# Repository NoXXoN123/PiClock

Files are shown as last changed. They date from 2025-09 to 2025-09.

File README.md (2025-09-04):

# PiClock
An Original design of an Analog Digital Clock featuring over 210 LEDs and full customization!

# License
Copyright 2025 NoXXoN

All Rights Reserved.

You may view, download, and manufacture physical copies of this PCB and schematic design for **personal, non-commercial use only** (e.g., DIY projects or prototyping).

You may **not**:
- Distribute, share, or sell the design files or derived works.
- Manufacture boards for sale, resale, or commercial deployment.
- Host or mirror this content online.

For commercial licensing, manufacturing rights, or redistribution permissions, please contact:
noxxonyt@gmail.com

This license applies to all files in this project unless explicitly stated otherwise.

# Schematic
Schematic <br>

# PCB and schematic files
PCB: https://github.com/NoXXoN123/PiClock/blob/main/ClockPi.kicad_pcb  
Schematic: https://github.com/NoXXoN123/PiClock/blob/main/ClockPi.kicad_sch  
Kicad_Pro: https://github.com/NoXXoN123/PiClock/blob/main/ClockPi.kicad_pro  
# How to install
Install Thonny, Install MicroPython on a Pi Pico, Save the code below as 'main.py' on the directory of the Raspberry Pi by opening File Manager in Thonny (View > Files) or use Save As and choose the Raspberry Pi.  
# Code:
main.py:

```
import time
from machine import Pin, PWM, ADC

def percent_to_duty(pct):
    return int((pct / 100.0) * 65535)

def get_light_level():
    raw = light_sensor.read_u16()     # 0–65535
    return raw >> 8                   # Scale to 0–255

def set_pwm_all(level):
    pwm_seconds.duty_u16(level)
    pwm_minutes.duty_u16(level)
    pwm_hours.duty_u16(level)

def light_control_loop():
    while True:
        light = get_light_level()

        if light < LIGHT_THRESHOLD:
            set_pwm_all(DIM_LEVEL)
        else:
            set_pwm_all(BRIGHT_LEVEL)

        time.sleep(0.1)  # Check every 100ms
def shift_out(data_pin, clock_pin, latch_pin, data_bytes):
    latch_pin.value(0)
    for byte in data_bytes:
        for bit in range(8):
            data_pin.value((byte >> (7 - bit)) & 1)
            clock_pin.value(1)
            clock_pin.value(0)
    latch_pin.value(1)
def seconds(*bits):
    # bits is a list of 64 bits for 8 chips * 8 bits
    # convert bits to bytes and send
    data_bytes = []
    for i in range(0, 64, 8):
        byte = 0
        for b in bits[i:i+8]:
            byte = (byte << 1) | (b & 1)
        data_bytes.append(byte)
    shift_out(DATA_PIN_SECONDS, CLOCK_PIN_SECONDS, LATCH_PIN_SECONDS, data_bytes)

def minutes(*bits):
    data_bytes = []
    for i in range(0, 64, 8):
        byte = 0
        for b in bits[i:i+8]:
            byte = (byte << 1) | (b & 1)
        data_bytes.append(byte)
    shift_out(DATA_PIN_MINUTES, CLOCK_PIN_MINUTES, LATCH_PIN_MINUTES, data_bytes)

def hours(*bits):
    data_bytes = []
    for i in range(0, 16, 8):
        byte = 0
        for b in bits[i:i+8]:
            byte = (byte << 1) | (b & 1)
        data_bytes.append(byte)
    shift_out(DATA_PIN_HOURS, CLOCK_PIN_HOURS, LATCH_PIN_HOURS, data_bytes)
def seconds(*bits):
    # your code to shift out bits to the seconds chips
    pass

def minutes(*bits):
    # same for minutes
    pass

def hours(*bits):
    # same for hours
    pass

# Pin setup - Don't touch this!
DATA_PIN_SECONDS = Pin(2, Pin.OUT)
CLOCK_PIN_SECONDS = Pin(3, Pin.OUT)
LATCH_PIN_SECONDS = Pin(4, Pin.OUT)

DATA_PIN_MINUTES = Pin(5, Pin.OUT)
CLOCK_PIN_MINUTES = Pin(6, Pin.OUT)
LATCH_PIN_MINUTES = Pin(7, Pin.OUT)

DATA_PIN_HOURS = Pin(9, Pin.OUT)
CLOCK_PIN_HOURS = Pin(8, Pin.OUT)
LATCH_PIN_HOURS = Pin(10, Pin.OUT)

PHOTORESISTOR_PIN = 26 # ADC0
PWM_SECONDS_PIN = 19
PWM_MINUTES_PIN = 20
PWM_HOURS_PIN = 21
BUTTON_HOUR = Pin(17, Pin.IN, Pin.PULL_DOWN)
BUTTON_MINUTE = Pin(16, Pin.IN, Pin.PULL_DOWN)
LED = Pin(25, Pin.OUT)
# Setup Variables - Don't touch this either!
SECOND_CHIPS = 8
MINUTE_CHIPS = 8
HOUR_CHIPS = 2
# USER SETTINGS - Touch this!
PWM_FREQ = 1000 #Hz DEFAULT: 1000
PWM_BRIGHT = percent_to_duty(60)  # DEFAULT: 60
PWM_DIM = percent_to_duty(10)     # DEFAULT: 10
LIGHT_THRESHOLD = 100 # DEFAULT: 100
# ---------------------
light_sensor = ADC(PHOTORESISTOR_PIN)
pwm_seconds = PWM(Pin(PWM_SECONDS_PIN))
pwm_minutes = PWM(Pin(PWM_MINUTES_PIN))
pwm_hours   = PWM(Pin(PWM_HOURS_PIN))
for pwm in (pwm_seconds, pwm_minutes, pwm_hours):
    pwm.freq(PWM_FREQ)

seconds_buffer = bytearray(SECOND_CHIPS)
minutes_buffer = bytearray(MINUTE_CHIPS)
hours_buffer = bytearray(HOUR_CHIPS)

# ---------------- Functions ----------------
def boot_animation_chase():
    for i in range(64):  # 64 steps for seconds and minutes
        sec_pattern = [0 if j == i else 1 for j in range(64)]
        min_pattern = [0 if j == (i + 20) % 64 else 1 for j in range(64)]  # offset for visual effect
        hr_pattern  = [0 if j == (i % 16) else 1 for j in range(16)]       # wrap 0–15

        seconds(*sec_pattern)
        minutes(*min_pattern)
        hours(*hr_pattern)

        time.sleep(0.03)

def fast_forward_boot(cycle_duration_sec=10):
    total_seconds = 12 * 60 * 60  # 12 hours = 43200 seconds
    delay = cycle_duration_sec / total_seconds

    for seconds_passed in range(total_seconds):
        sec = seconds_passed % 60
        min = (seconds_passed // 60) % 60
        hr  = (seconds_passed // 3600) % 12  # 12-hour format

        sec_buf = [1] * 64
        sec_buf[sec] = 0  # active low
        seconds(*sec_buf)

        min_buf = [1] * 64
        min_buf[min] = 0
        minutes(*min_buf)

        hr_buf = [1] * 16
        hr_buf[hr] = 0
        hours(*hr_buf)

        time.sleep(delay)

def run_clock():
    last_sec_update = 0
    last_min_update = 0
    last_hour_update = 0

    sec = 0
    minute = 0
    hour = 0

    last_button_hour = 0
    last_button_minute = 0
    debounce_ms = 200  # debounce delay

    led_on_time = 0
    led_duration = 200  # ms to keep LED on visibly

    while True:
        now = time.ticks_ms()

        if BUTTON_HOUR.value() == 1 and time.ticks_diff(now, last_button_hour) > debounce_ms:
            hour = (hour + 1) % 12
            hours(*[0 if i == hour else 1 for i in range(16)])
            last_button_hour = now
            last_hour_update = now

        if BUTTON_MINUTE.value() == 1 and time.ticks_diff(now, last_button_minute) > debounce_ms:
            minute = (minute + 1) % 60
            minutes(*[0 if i == minute else 1 for i in range(64)])
            last_button_minute = now
            last_min_update = now

        if time.ticks_diff(now, last_sec_update) >= 1000:
            sec = (sec + 1) % 60
            seconds(*[0 if i == sec else 1 for i in range(64)])
            last_sec_update = now

            LED.value(1)
            led_on_time = now

        if LED.value() == 1 and time.ticks_diff(now, led_on_time) > led_duration:
            LED.value(0)

        if time.ticks_diff(now, last_min_update) >= 60000:
            minute = (minute + 1) % 60
            minutes(*[0 if i == minute else 1 for i in range(64)])
            last_min_update = now

        if time.ticks_diff(now, last_hour_update) >= 3600000:
            hour = (hour + 1) % 12
            hours(*[0 if i == hour else 1 for i in range(16)])
            last_hour_update = now

        light = get_light_level()
        if light < LIGHT_THRESHOLD:
            set_pwm_all(PWM_DIM)
        else:
            set_pwm_all(PWM_BRIGHT)

        time.sleep(0.01) 

boot_animation_chase()
fast_forward_boot(10) # <-- 10 Seconds
run_clock()
```

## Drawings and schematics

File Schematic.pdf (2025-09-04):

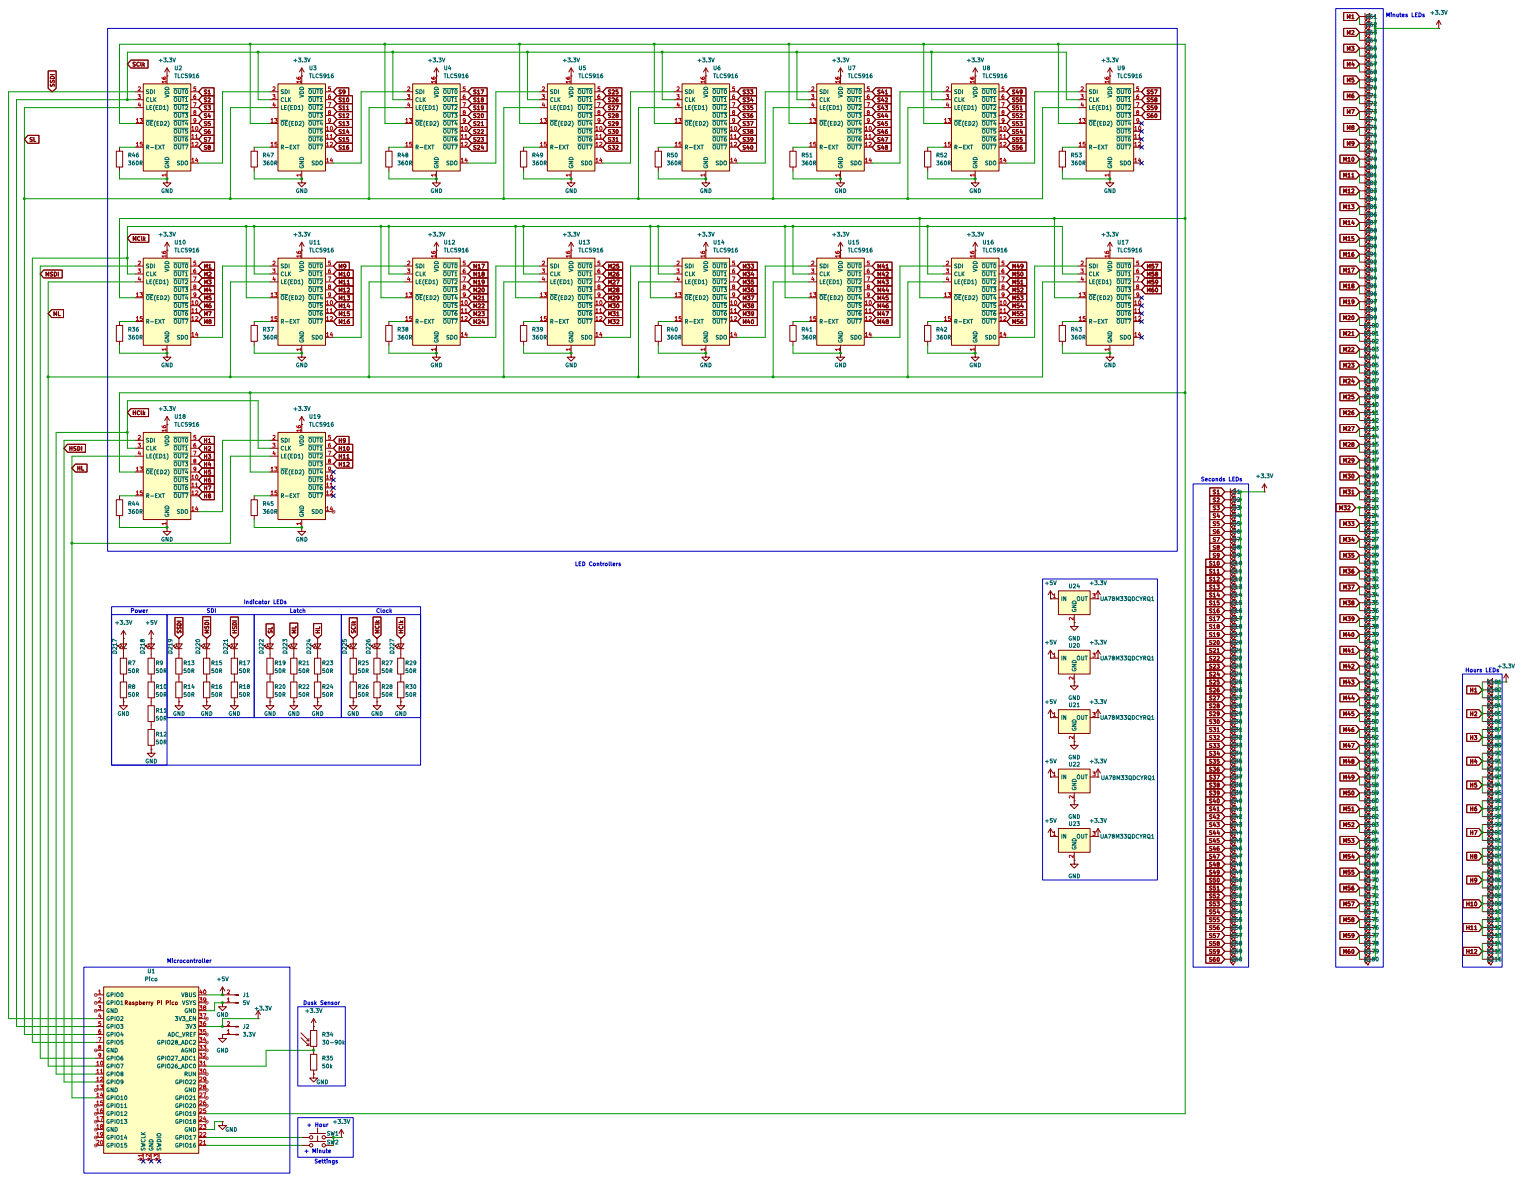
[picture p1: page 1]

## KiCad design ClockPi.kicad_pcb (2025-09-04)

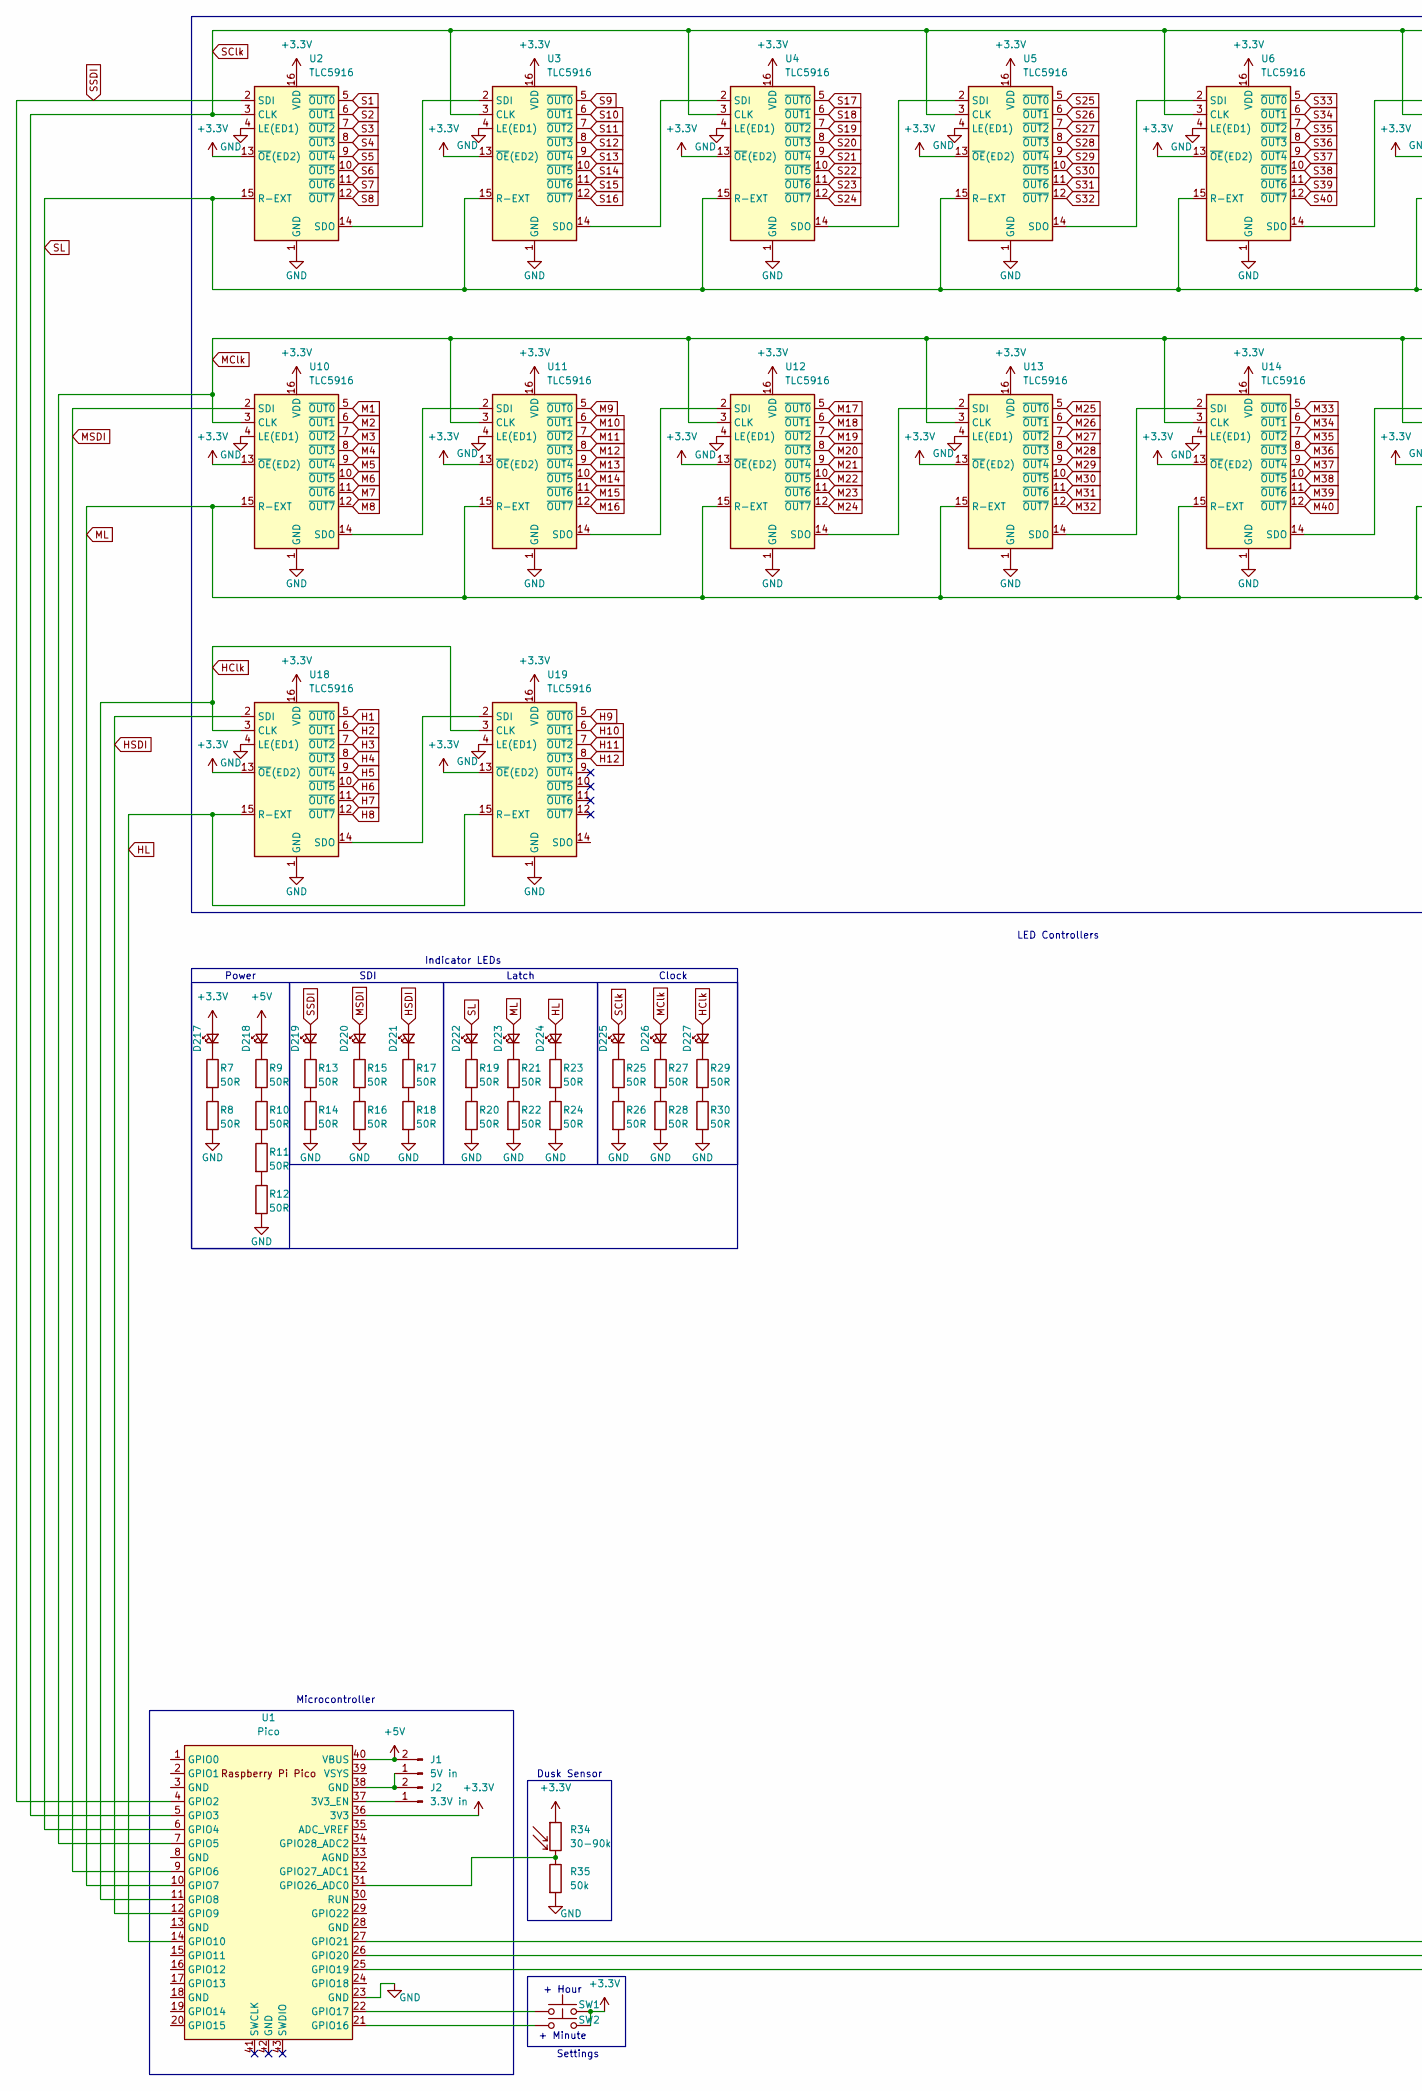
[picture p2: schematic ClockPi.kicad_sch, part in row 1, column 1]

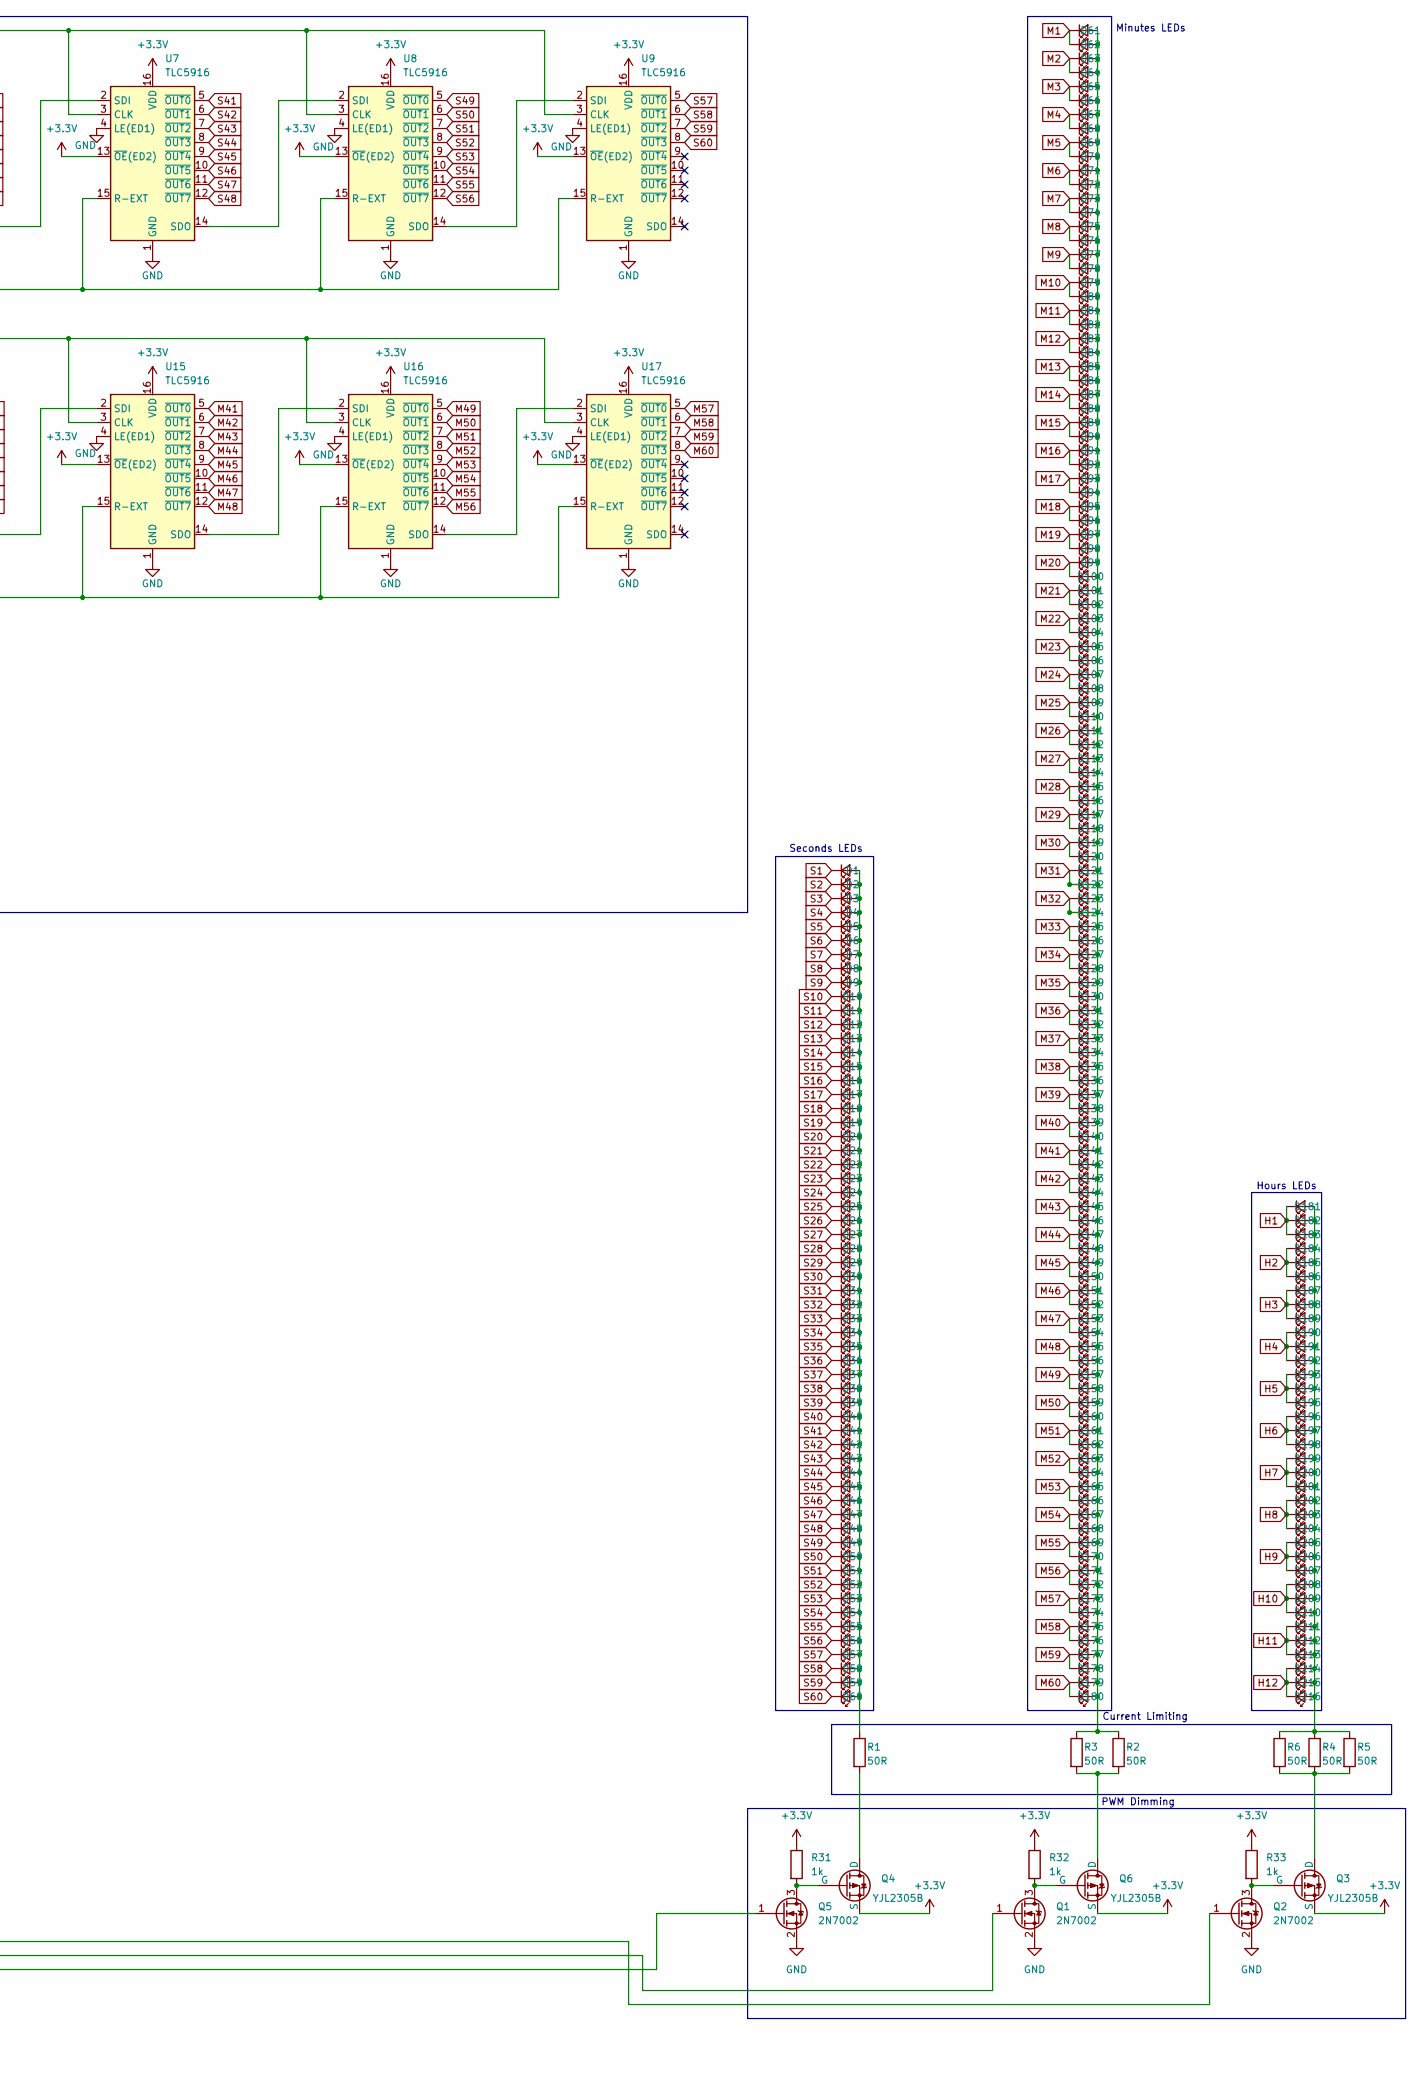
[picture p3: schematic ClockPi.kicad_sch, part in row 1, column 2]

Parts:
D1, D2, D3, D4, D5, D6, D7, D8, D9, D10, D11, D12, D13, D14, D15, D16, D17, D18, D19, D20, D21, D22, D23, D24, D25, D26, D27, D28, D29, D30, D31, D32, D33, D34, D35, D36, D37, D38, D39, D40, D41, D42, D43, D44, D45, D46, D47, D48, D49, D50, D51, D52, D53, D54, D55, D56, D57, D58, D59, D60, D61, D62, D63, D64, D65, D66, D67, D68, D69, D70, D71, D72, D73, D74, D75, D76, D77, D78, D79, D80, D81, D82, D83, D84, D85, D86, D87, D88, D89, D90, D91, D92, D93, D94, D95, D96, D97, D98, D99, D100, D101, D102, D103, D104, D105, D106, D107, D108, D109, D110, D111, D112, D113, D114, D115, D116, D117, D118, D119, D120, D121, D122, D123, D124, D125, D126, D127, D128, D129, D130, D131, D132, D133, D134, D135, D136, D137, D138, D139, D140, D141, D142, D143, D144, D145, D146, D147, D148, D149, D150, D151, D152, D153, D154, D155, D156, D157, D158, D159, D160, D161, D162, D163, D164, D165, D166, D167, D168, D169, D170, D171, D172, D173, D174, D175, D176, D177, D178, D179, D180, D181, D182, D183, D184, D185, D186, D187, D188, D189, D190, D191, D192, D193, D194, D195, D196, D197, D198, D199, D200, D201, D202, D203, D204, D205, D206, D207, D208, D209, D210, D211, D212, D213, D214, D215, D216, D217, D218, D219, D220, D221, D222, D223, D224, D225, D226, D227: LED_Small; LED_0805_2012Metric_Pad1.15x1.40mm_HandSolder
J1: 5V in; PinHeader_1x02_P2.54mm_Vertical
J2: 3.3V in; PinHeader_1x02_P2.54mm_Vertical
Q1, Q2, Q5: 2N7002; SOT-23
Q3, Q4, Q6: YJL2305B; SOT-323_SC-70_Handsoldering
R1, R2, R3, R4, R5, R6, R7, R8, R9, R10, R11, R12, R13, R14, R15, R16, R17, R18, R19, R20, R21, R22, R23, R24, R25, R26, R27, R28, R29, R30: 50R; R_0402_1005Metric_Pad0.72x0.64mm_HandSolder
R31, R32, R33: 1k; R_0402_1005Metric_Pad0.72x0.64mm_HandSolder
R34: 30-90k; R_LDR_5.1x4.3mm_P3.4mm_Vertical
R35: 50k; R_0402_1005Metric_Pad0.72x0.64mm_HandSolder
SW1, SW2: SW_Push; SW_DIP_SPSTx01_Slide_6.7x4.1mm_W6.73mm_P2.54mm_LowProfile_J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
U1: Pico; RaspberryPi_Pico_SMD_HandSolder
U2, U3, U4, U5, U6, U7, U8, U9, U10, U11, U12, U13, U14, U15, U16, U17, U18, U19: TLC5916; SO-16_3.9x9.9mm_P1.27mm

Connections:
+3.3V: D217.2 (A), Q3.3 (S), Q4.3 (S), Q6.3 (S), R31.1, R32.1, R33.1, R34.1, SW1.2, SW2.2, U1.36 (3V3), U2.13 (~OE(ED2)), U2.16 (VDD), U3.13 (~OE(ED2)), U3.16 (VDD), U4.13 (~OE(ED2)), U4.16 (VDD), U5.13 (~OE(ED2)), U5.16 (VDD), U6.13 (~OE(ED2)), U6.16 (VDD), U7.13 (~OE(ED2)), U7.16 (VDD), U8.13 (~OE(ED2)), U8.16 (VDD), U9.13 (~OE(ED2)), U9.16 (VDD), U10.13 (~OE(ED2)), U10.16 (VDD), U11.13 (~OE(ED2)), U11.16 (VDD), U12.13 (~OE(ED2)), U12.16 (VDD), U13.13 (~OE(ED2)), U13.16 (VDD), U14.13 (~OE(ED2)), U14.16 (VDD), U15.13 (~OE(ED2)), U15.16 (VDD), U16.13 (~OE(ED2)), U16.16 (VDD), U17.13 (~OE(ED2)), U17.16 (VDD), U18.13 (~OE(ED2)), U18.16 (VDD), U19.13 (~OE(ED2)), U19.16 (VDD)
+5V: D218.2 (A), J1.2, U1.40 (VBUS)
GND: Q1.2 (S), Q2.2 (S), Q5.2 (S), R8.2, R12.2, R14.2, R16.2, R18.2, R20.2, R22.2, R24.2, R26.2, R28.2, R30.2, R35.2, U1.23 (GND), U2.1 (GND), U2.4 (LE(ED1)), U3.1 (GND), U3.4 (LE(ED1)), U4.1 (GND), U4.4 (LE(ED1)), U5.1 (GND), U5.4 (LE(ED1)), U6.1 (GND), U6.4 (LE(ED1)), U7.1 (GND), U7.4 (LE(ED1)), U8.1 (GND), U8.4 (LE(ED1)), U9.1 (GND), U9.4 (LE(ED1)), U10.1 (GND), U10.4 (LE(ED1)), U11.1 (GND), U11.4 (LE(ED1)), U12.1 (GND), U12.4 (LE(ED1)), U13.1 (GND), U13.4 (LE(ED1)), U14.1 (GND), U14.4 (LE(ED1)), U15.1 (GND), U15.4 (LE(ED1)), U16.1 (GND), U16.4 (LE(ED1)), U17.1 (GND), U17.4 (LE(ED1)), U18.1 (GND), U18.4 (LE(ED1)), U19.1 (GND), U19.4 (LE(ED1))
H1: D181.1 (K), D182.1 (K), D183.1 (K), U18.5 (~OUT0)
H2: D184.1 (K), D185.1 (K), D186.1 (K), U18.6 (~OUT1)
H3: D187.1 (K), D188.1 (K), D189.1 (K), U18.7 (~OUT2)
H4: D190.1 (K), D191.1 (K), D192.1 (K), U18.8 (~OUT3)
H5: D193.1 (K), D194.1 (K), D195.1 (K), U18.9 (~OUT4)
H6: D196.1 (K), D197.1 (K), D198.1 (K), U18.10 (~OUT5)
H7: D199.1 (K), D200.1 (K), D201.1 (K), U18.11 (~OUT6)
H8: D202.1 (K), D203.1 (K), D204.1 (K), U18.12 (~OUT7)
H9: D205.1 (K), D206.1 (K), D207.1 (K), U19.5 (~OUT0)
H10: D208.1 (K), D209.1 (K), D210.1 (K), U19.6 (~OUT1)
H11: D211.1 (K), D212.1 (K), D213.1 (K), U19.7 (~OUT2)
H12: D214.1 (K), D215.1 (K), D216.1 (K), U19.8 (~OUT3)
HClk: D227.2 (A), U1.11 (GPIO8), U18.3 (CLK), U19.3 (CLK)
HL: D224.2 (A), U1.14 (GPIO10), U18.15 (R-EXT), U19.15 (R-EXT)
HSDI: D221.2 (A), U1.12 (GPIO9), U18.2 (SDI)
M1: D61.1 (K), D62.1 (K), U10.5 (~OUT0)
M2: D63.1 (K), D64.1 (K), U10.6 (~OUT1)
M3: D65.1 (K), D66.1 (K), U10.7 (~OUT2)
M4: D67.1 (K), D68.1 (K), U10.8 (~OUT3)
M5: D69.1 (K), D70.1 (K), U10.9 (~OUT4)
M6: D71.1 (K), D72.1 (K), U10.10 (~OUT5)
M7: D73.1 (K), D74.1 (K), U10.11 (~OUT6)
M8: D75.1 (K), D76.1 (K), U10.12 (~OUT7)
M9: D77.1 (K), D78.1 (K), U11.5 (~OUT0)
M10: D79.1 (K), D80.1 (K), U11.6 (~OUT1)
M11: D81.1 (K), D82.1 (K), U11.7 (~OUT2)
M12: D83.1 (K), D84.1 (K), U11.8 (~OUT3)
M13: D85.1 (K), D86.1 (K), U11.9 (~OUT4)
M14: D87.1 (K), D88.1 (K), U11.10 (~OUT5)
M15: D89.1 (K), D90.1 (K), U11.11 (~OUT6)
M16: D91.1 (K), D92.1 (K), U11.12 (~OUT7)
M17: D93.1 (K), D94.1 (K), U12.5 (~OUT0)
M18: D95.1 (K), D96.1 (K), U12.6 (~OUT1)
M19: D97.1 (K), D98.1 (K), U12.7 (~OUT2)
M20: D99.1 (K), D100.1 (K), U12.8 (~OUT3)
M21: D101.1 (K), D102.1 (K), U12.9 (~OUT4)
M22: D103.1 (K), D104.1 (K), U12.10 (~OUT5)
M23: D105.1 (K), D106.1 (K), U12.11 (~OUT6)
M24: D107.1 (K), D108.1 (K), U12.12 (~OUT7)
M25: D109.1 (K), D110.1 (K), U13.5 (~OUT0)
M26: D111.1 (K), D112.1 (K), U13.6 (~OUT1)
M27: D113.1 (K), D114.1 (K), U13.7 (~OUT2)
M28: D115.1 (K), D116.1 (K), U13.8 (~OUT3)
M29: D117.1 (K), D118.1 (K), U13.9 (~OUT4)
M30: D119.1 (K), D120.1 (K), U13.10 (~OUT5)
M31: D61.2 (A), D62.2 (A), D63.2 (A), D64.2 (A), D65.2 (A), D66.2 (A), D67.2 (A), D68.2 (A), D69.2 (A), D70.2 (A), D71.2 (A), D72.2 (A), D73.2 (A), D74.2 (A), D75.2 (A), D76.2 (A), D77.2 (A), D78.2 (A), D79.2 (A), D80.2 (A), D81.2 (A), D82.2 (A), D83.2 (A), D84.2 (A), D85.2 (A), D86.2 (A), D87.2 (A), D88.2 (A), D89.2 (A), D90.2 (A), D91.2 (A), D92.2 (A), D93.2 (A), D94.2 (A), D95.2 (A), D96.2 (A), D97.2 (A), D98.2 (A), D99.2 (A), D100.2 (A), D101.2 (A), D102.2 (A), D103.2 (A), D104.2 (A), D105.2 (A), D106.2 (A), D107.2 (A), D108.2 (A), D109.2 (A), D110.2 (A), D111.2 (A), D112.2 (A), D113.2 (A), D114.2 (A), D115.2 (A), D116.2 (A), D117.2 (A), D118.2 (A), D119.2 (A), D120.2 (A), D121.1 (K), D121.2 (A), D122.1 (K), D122.2 (A), D123.1 (K), D123.2 (A), D124.1 (K), D124.2 (A), D125.2 (A), D126.2 (A), D127.2 (A), D128.2 (A), D129.2 (A), D130.2 (A), D131.2 (A), D132.2 (A), D133.2 (A), D134.2 (A), D135.2 (A), D136.2 (A), D137.2 (A), D138.2 (A), D139.2 (A), D140.2 (A), D141.2 (A), D142.2 (A), D143.2 (A), D144.2 (A), D145.2 (A), D146.2 (A), D147.2 (A), D148.2 (A), D149.2 (A), D150.2 (A), D151.2 (A), D152.2 (A), D153.2 (A), D154.2 (A), D155.2 (A), D156.2 (A), D157.2 (A), D158.2 (A), D159.2 (A), D160.2 (A), D161.2 (A), D162.2 (A), D163.2 (A), D164.2 (A), D165.2 (A), D166.2 (A), D167.2 (A), D168.2 (A), D169.2 (A), D170.2 (A), D171.2 (A), D172.2 (A), D173.2 (A), D174.2 (A), D175.2 (A), D176.2 (A), D177.2 (A), D178.2 (A), D179.2 (A), D180.2 (A), R2.1, R3.1, U13.11 (~OUT6), U13.12 (~OUT7)
M33: D125.1 (K), D126.1 (K), U14.5 (~OUT0)
M34: D127.1 (K), D128.1 (K), U14.6 (~OUT1)
M35: D129.1 (K), D130.1 (K), U14.7 (~OUT2)
M36: D131.1 (K), D132.1 (K), U14.8 (~OUT3)
M37: D133.1 (K), D134.1 (K), U14.9 (~OUT4)
M38: D135.1 (K), D136.1 (K), U14.10 (~OUT5)
M39: D137.1 (K), D138.1 (K), U14.11 (~OUT6)
M40: D139.1 (K), D140.1 (K), U14.12 (~OUT7)
M41: D141.1 (K), D142.1 (K), U15.5 (~OUT0)
M42: D143.1 (K), D144.1 (K), U15.6 (~OUT1)
M43: D145.1 (K), D146.1 (K), U15.7 (~OUT2)
M44: D147.1 (K), D148.1 (K), U15.8 (~OUT3)
M45: D149.1 (K), D150.1 (K), U15.9 (~OUT4)
M46: D151.1 (K), D152.1 (K), U15.10 (~OUT5)
M47: D153.1 (K), D154.1 (K), U15.11 (~OUT6)
M48: D155.1 (K), D156.1 (K), U15.12 (~OUT7)
M49: D157.1 (K), D158.1 (K), U16.5 (~OUT0)
M50: D159.1 (K), D160.1 (K), U16.6 (~OUT1)
M51: D161.1 (K), D162.1 (K), U16.7 (~OUT2)
M52: D163.1 (K), D164.1 (K), U16.8 (~OUT3)
M53: D165.1 (K), D166.1 (K), U16.9 (~OUT4)
M54: D167.1 (K), D168.1 (K), U16.10 (~OUT5)
M55: D169.1 (K), D170.1 (K), U16.11 (~OUT6)
M56: D171.1 (K), D172.1 (K), U16.12 (~OUT7)
M57: D173.1 (K), D174.1 (K), U17.5 (~OUT0)
M58: D175.1 (K), D176.1 (K), U17.6 (~OUT1)
M59: D177.1 (K), D178.1 (K), U17.7 (~OUT2)
M60: D179.1 (K), D180.1 (K), U17.8 (~OUT3)
MClk: D226.2 (A), U1.7 (GPIO5), U10.3 (CLK), U11.3 (CLK), U12.3 (CLK), U13.3 (CLK), U14.3 (CLK), U15.3 (CLK), U16.3 (CLK), U17.3 (CLK)
ML: D223.2 (A), U1.10 (GPIO7), U10.15 (R-EXT), U11.15 (R-EXT), U12.15 (R-EXT), U13.15 (R-EXT), U14.15 (R-EXT), U15.15 (R-EXT), U16.15 (R-EXT), U17.15 (R-EXT)
MSDI: D220.2 (A), U1.9 (GPIO6), U10.2 (SDI)
unnamed: D1.2 (A), D2.2 (A), D3.2 (A), D4.2 (A), D5.2 (A), D6.2 (A), D7.2 (A), D8.2 (A), D9.2 (A), D10.2 (A), D11.2 (A), D12.2 (A), D13.2 (A), D14.2 (A), D15.2 (A), D16.2 (A), D17.2 (A), D18.2 (A), D19.2 (A), D20.2 (A), D21.2 (A), D22.2 (A), D23.2 (A), D24.2 (A), D25.2 (A), D26.2 (A), D27.2 (A), D28.2 (A), D29.2 (A), D30.2 (A), D31.2 (A), D32.2 (A), D33.2 (A), D34.2 (A), D35.2 (A), D36.2 (A), D37.2 (A), D38.2 (A), D39.2 (A), D40.2 (A), D41.2 (A), D42.2 (A), D43.2 (A), D44.2 (A), D45.2 (A), D46.2 (A), D47.2 (A), D48.2 (A), D49.2 (A), D50.2 (A), D51.2 (A), D52.2 (A), D53.2 (A), D54.2 (A), D55.2 (A), D56.2 (A), D57.2 (A), D58.2 (A), D59.2 (A), D60.2 (A), R1.1
unnamed: D181.2 (A), D182.2 (A), D183.2 (A), D184.2 (A), D185.2 (A), D186.2 (A), D187.2 (A), D188.2 (A), D189.2 (A), D190.2 (A), D191.2 (A), D192.2 (A), D193.2 (A), D194.2 (A), D195.2 (A), D196.2 (A), D197.2 (A), D198.2 (A), D199.2 (A), D200.2 (A), D201.2 (A), D202.2 (A), D203.2 (A), D204.2 (A), D205.2 (A), D206.2 (A), D207.2 (A), D208.2 (A), D209.2 (A), D210.2 (A), D211.2 (A), D212.2 (A), D213.2 (A), D214.2 (A), D215.2 (A), D216.2 (A), R4.1, R5.1, R6.1
unnamed: D217.1 (K), R7.1
unnamed: D218.1 (K), R9.1
unnamed: D219.1 (K), R13.1
unnamed: D220.1 (K), R15.1
unnamed: D221.1 (K), R17.1
unnamed: D222.1 (K), R19.1
unnamed: D223.1 (K), R21.1
unnamed: D224.1 (K), R23.1
unnamed: D225.1 (K), R25.1
unnamed: D226.1 (K), R27.1
unnamed: D227.1 (K), R29.1
unnamed: J1.1, J2.2, U1.38 (GND)
unnamed: J2.1, U1.37 (3V3_EN)
unnamed: Q1.3 (D), Q6.2 (G), R32.2
unnamed: Q1.1 (G), U1.26 (GPIO20)
unnamed: Q2.3 (D), Q3.2 (G), R33.2
unnamed: Q2.1 (G), U1.27 (GPIO21)
unnamed: Q3.1 (D), R4.2, R5.2, R6.2
unnamed: Q4.1 (D), R1.2
unnamed: Q4.2 (G), Q5.3 (D), R31.2
unnamed: Q5.1 (G), U1.25 (GPIO19)
unnamed: Q6.1 (D), R2.2, R3.2
unnamed: R7.2, R8.1
unnamed: R9.2, R10.1
unnamed: R10.2, R11.1
unnamed: R11.2, R12.1
unnamed: R13.2, R14.1
unnamed: R15.2, R16.1
unnamed: R17.2, R18.1
unnamed: R19.2, R20.1
unnamed: R21.2, R22.1
unnamed: R23.2, R24.1
unnamed: R25.2, R26.1
unnamed: R27.2, R28.1
unnamed: R29.2, R30.1
unnamed: SW2.1, U1.21 (GPIO16)
unnamed: SW1.1, U1.22 (GPIO17)
unnamed: R34.2, R35.1, U1.31 (GPIO26_ADC0)
unnamed: U2.14 (SDO), U3.2 (SDI)
unnamed: U3.14 (SDO), U4.2 (SDI)
unnamed: U4.14 (SDO), U5.2 (SDI)
unnamed: U5.14 (SDO), U6.2 (SDI)
unnamed: U6.14 (SDO), U7.2 (SDI)
unnamed: U7.14 (SDO), U8.2 (SDI)
unnamed: U8.14 (SDO), U9.2 (SDI)
unnamed: U10.14 (SDO), U11.2 (SDI)
unnamed: U11.14 (SDO), U12.2 (SDI)
unnamed: U12.14 (SDO), U13.2 (SDI)
unnamed: U13.14 (SDO), U14.2 (SDI)
unnamed: U14.14 (SDO), U15.2 (SDI)
unnamed: U15.14 (SDO), U16.2 (SDI)
unnamed: U16.14 (SDO), U17.2 (SDI)
unnamed: U18.14 (SDO), U19.2 (SDI)
S1: D1.1 (K), U2.5 (~OUT0)
S2: D2.1 (K), U2.6 (~OUT1)
S3: D3.1 (K), U2.7 (~OUT2)
S4: D4.1 (K), U2.8 (~OUT3)
S5: D5.1 (K), U2.9 (~OUT4)
S6: D6.1 (K), U2.10 (~OUT5)
S7: D7.1 (K), U2.11 (~OUT6)
S8: D8.1 (K), U2.12 (~OUT7)
S9: D9.1 (K), U3.5 (~OUT0)
S10: D10.1 (K), U3.6 (~OUT1)
S11: D11.1 (K), U3.7 (~OUT2)
S12: D12.1 (K), U3.8 (~OUT3)
S13: D13.1 (K), U3.9 (~OUT4)
S14: D14.1 (K), U3.10 (~OUT5)
S15: D15.1 (K), U3.11 (~OUT6)
S16: D16.1 (K), U3.12 (~OUT7)
S17: D17.1 (K), U4.5 (~OUT0)
S18: D18.1 (K), U4.6 (~OUT1)
S19: D19.1 (K), U4.7 (~OUT2)
S20: D20.1 (K), U4.8 (~OUT3)
S21: D21.1 (K), U4.9 (~OUT4)
S22: D22.1 (K), U4.10 (~OUT5)
S23: D23.1 (K), U4.11 (~OUT6)
S24: D24.1 (K), U4.12 (~OUT7)
S25: D25.1 (K), U5.5 (~OUT0)
S26: D26.1 (K), U5.6 (~OUT1)
S27: D27.1 (K), U5.7 (~OUT2)
S28: D28.1 (K), U5.8 (~OUT3)
S29: D29.1 (K), U5.9 (~OUT4)
S30: D30.1 (K), U5.10 (~OUT5)
S31: D31.1 (K), U5.11 (~OUT6)
S32: D32.1 (K), U5.12 (~OUT7)
S33: D33.1 (K), U6.5 (~OUT0)
S34: D34.1 (K), U6.6 (~OUT1)
S35: D35.1 (K), U6.7 (~OUT2)
S36: D36.1 (K), U6.8 (~OUT3)
S37: D37.1 (K), U6.9 (~OUT4)
S38: D38.1 (K), U6.10 (~OUT5)
S39: D39.1 (K), U6.11 (~OUT6)
S40: D40.1 (K), U6.12 (~OUT7)
S41: D41.1 (K), U7.5 (~OUT0)
S42: D42.1 (K), U7.6 (~OUT1)
S43: D43.1 (K), U7.7 (~OUT2)
S44: D44.1 (K), U7.8 (~OUT3)
S45: D45.1 (K), U7.9 (~OUT4)
S46: D46.1 (K), U7.10 (~OUT5)
S47: D47.1 (K), U7.11 (~OUT6)
S48: D48.1 (K), U7.12 (~OUT7)
S49: D49.1 (K), U8.5 (~OUT0)
S50: D50.1 (K), U8.6 (~OUT1)
S51: D51.1 (K), U8.7 (~OUT2)
S52: D52.1 (K), U8.8 (~OUT3)
S53: D53.1 (K), U8.9 (~OUT4)
S54: D54.1 (K), U8.10 (~OUT5)
S55: D55.1 (K), U8.11 (~OUT6)
S56: D56.1 (K), U8.12 (~OUT7)
S57: D57.1 (K), U9.5 (~OUT0)
S58: D58.1 (K), U9.6 (~OUT1)
S59: D59.1 (K), U9.7 (~OUT2)
S60: D60.1 (K), U9.8 (~OUT3)
SClk: D225.2 (A), U1.5 (GPIO3), U2.3 (CLK), U3.3 (CLK), U4.3 (CLK), U5.3 (CLK), U6.3 (CLK), U7.3 (CLK), U8.3 (CLK), U9.3 (CLK)
SL: D222.2 (A), U1.6 (GPIO4), U2.15 (R-EXT), U3.15 (R-EXT), U4.15 (R-EXT), U5.15 (R-EXT), U6.15 (R-EXT), U7.15 (R-EXT), U8.15 (R-EXT), U9.15 (R-EXT)
SSDI: D219.2 (A), U1.4 (GPIO2), U2.2 (SDI)

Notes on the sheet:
Microcontroller
Indicator LEDs
Settings
LED Controllers
Power
+ Minute
Seconds LEDs
SDI
PWM Dimming
Minutes LEDs
Dusk Sensor
Current Limiting
Hours LEDs
Latch
+ Hour
Clock

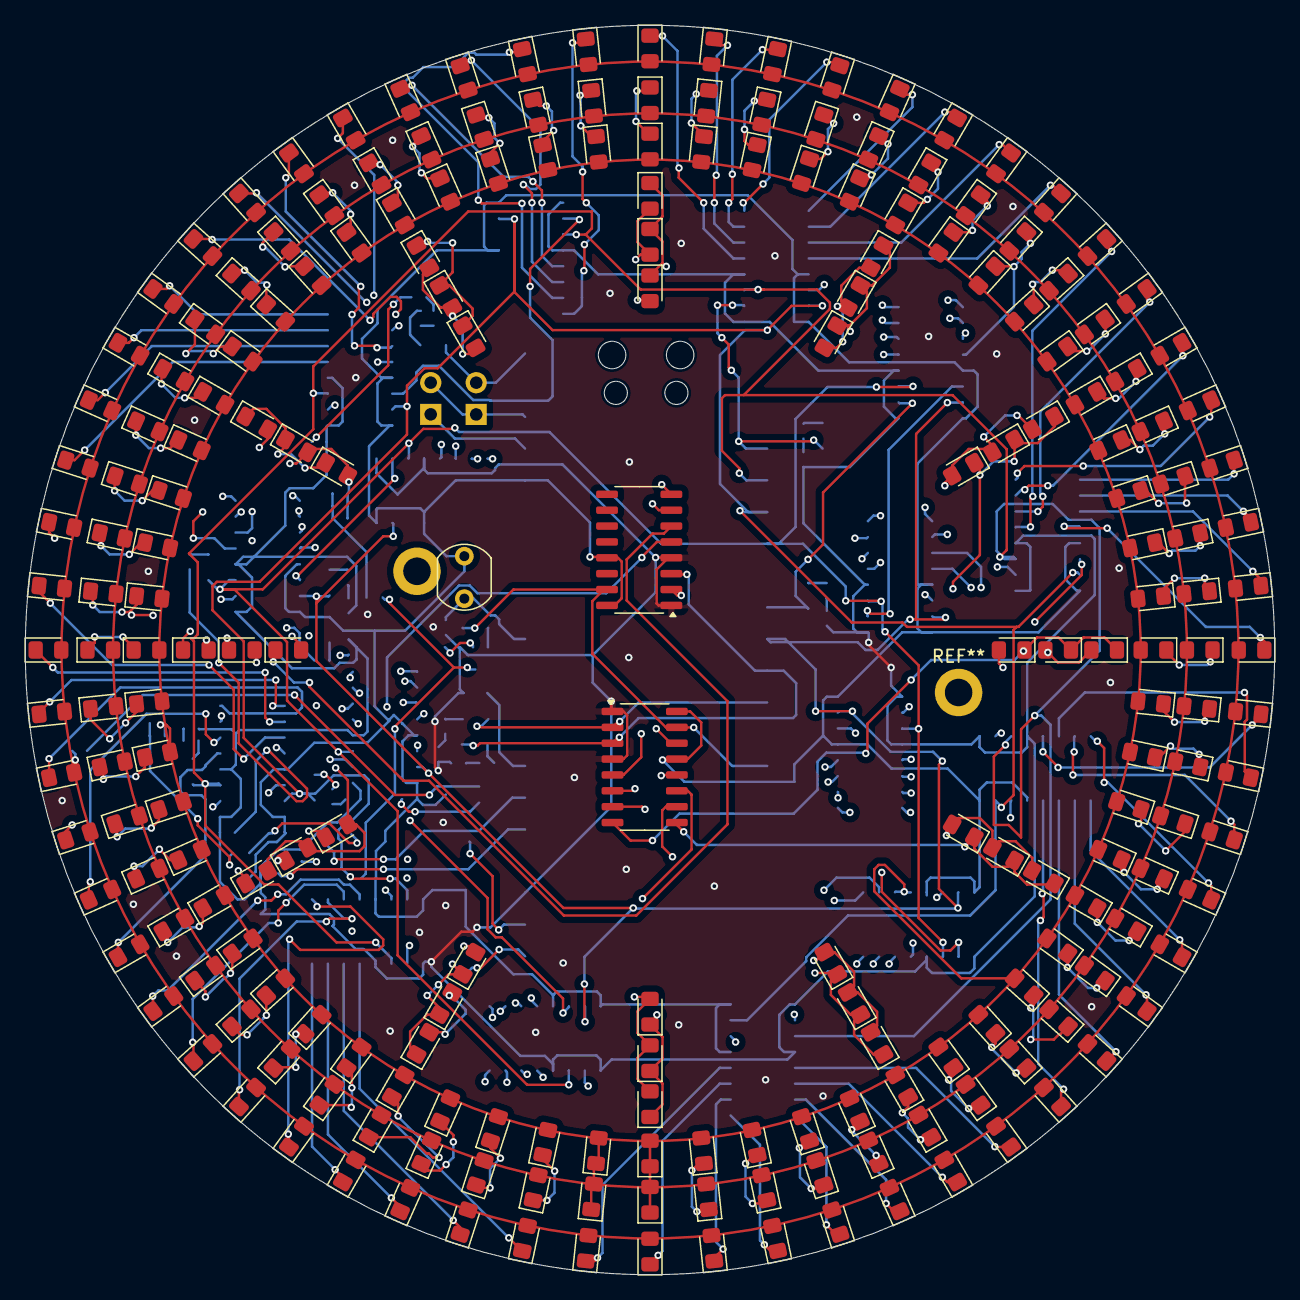
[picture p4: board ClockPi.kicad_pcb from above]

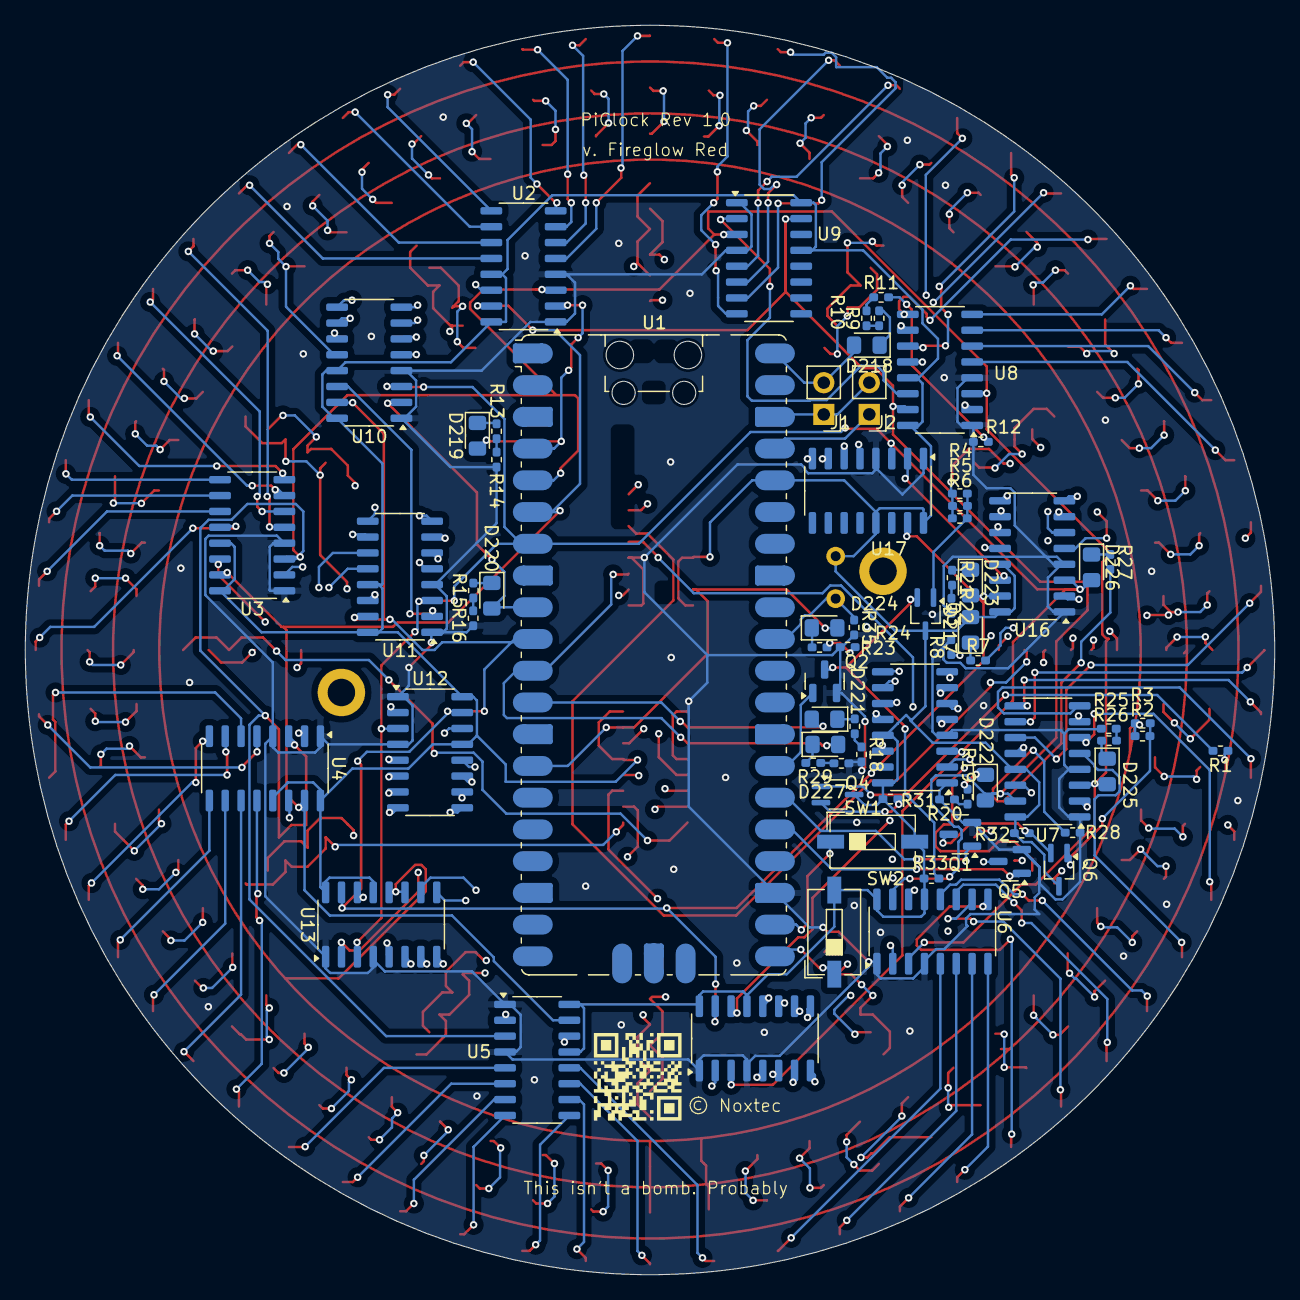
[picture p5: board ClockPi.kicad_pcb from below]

Board: 4 copper layers, 100.0 x 100.0 mm, 291 parts (72 on the bottom side), 198 nets.

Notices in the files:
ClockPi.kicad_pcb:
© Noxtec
